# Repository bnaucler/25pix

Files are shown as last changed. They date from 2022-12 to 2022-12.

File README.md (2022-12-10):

# 25pix game console
A simple game console with a 25 pixel 'screen' built of WS2812 LEDs

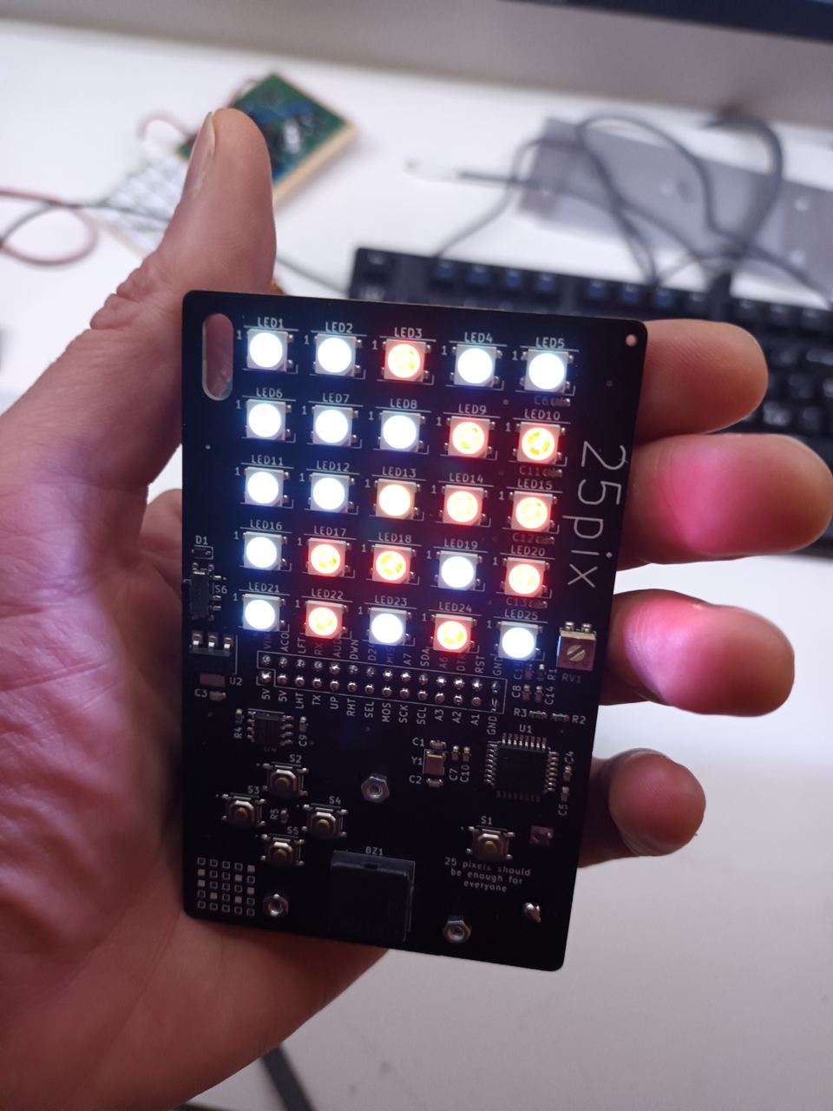
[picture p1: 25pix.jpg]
25pix


## Created by
Björn Westerberg Nauclér (mail@bnaucler.se) 2022

## Installation
The software is created with [PlatformIO](https://platformio.org) core and can be installed with `pio run -t upload`  
Edit `platformio.ini` to set upload port

## Software
Configuration can be done by editing macros in `src/25pix_config.h`.  

## Hardware
In the `kicad` sub-directory you can find [KiCad](https://kicad.org) files. If you prefer to send to production as is, the `hw_production` sub-directory has all gerbers, POS/CPL file and BOM in the correct format for ordering from [JLCPCB](https://jlcpcb.com).

## Contributing
Submit an issue or send a pull request if you feel inclined to get involved.

## Disclaimer
This project is in alpha version and, albeit usable, far from polished.  
Feel free to explore (and edit!) the code base, but expect bugs.

## License
MIT (do whatever you want)

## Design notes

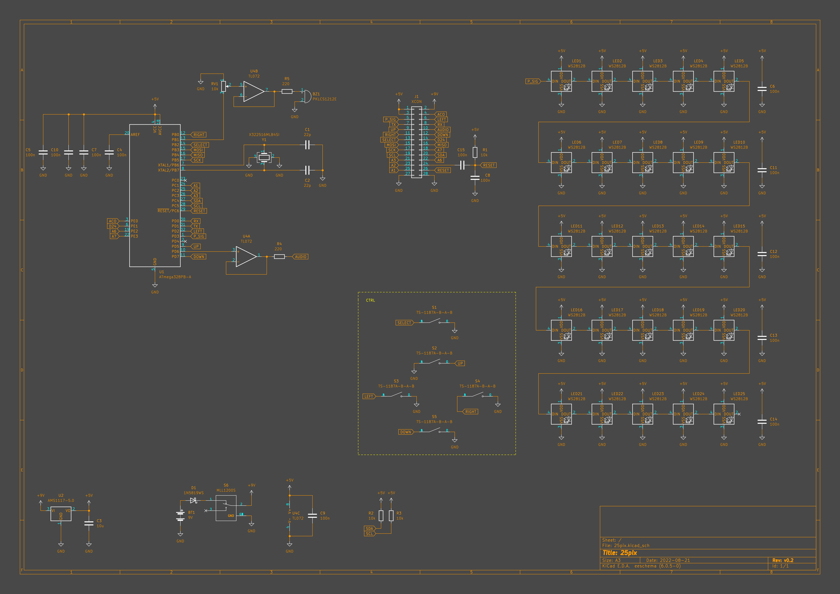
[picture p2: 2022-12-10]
kicad/25pix_rev01_schematic.png

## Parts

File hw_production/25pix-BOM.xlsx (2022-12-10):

25pix
Comment | Designator | Footprint | LCSC Part Number
PKLCS1212E | BZ1 | Buzzer_Beeper:Buzzer_Murata_PKLCS1212E | C113159
22p | C1,C2 | Capacitor_SMD:C_0603_1608Metric | C1653
10u | C3 | Capacitor_SMD:C_0603_1608Metric | C96446
100n | C4,C5,C6,C7,C8,C9,C10,C11,C12,C13,C14,C15 | Capacitor_SMD:C_0603_1608Metric | C14663
1N5819WS | D1 | Diode_SMD:D_SOD-323 | C191023
WS2812B | LED1,LED2,LED3,LED4,LED5,LED6,LED7,LED8,LED9,LED10,LED11,LED12,LED13,LED14,LED15,LED16,LED17,LED18,LED19,LED20,LED21,LED22,LED23,LED24,LED25 | LED_SMD:LED_WS2812B_PLCC4_5.0x5.0mm_P3.2mm | C2843785
10k | R1,R2,R3 | Resistor_SMD:R_0603_1608Metric | C25804
220 | R4,R5 | Resistor_SMD:R_0603_1608Metric | C22962
10k | RV1 | Potentiometer_SMD:Potentiometer_Bourns_3314G_Vertical | C780220
TS-1187A-B-A-B | S1,S2,S3,S4,S5 | SMD | C318884
SSSS811101 | S6 | SMD | C109335
ATmega328PB-A | U1 | Package_QFP:TQFP-32_7x7mm_P0.8mm | C132230
AMS1117-5.0 | U2 | Package_TO_SOT_SMD:SOT-223-3_TabPin2 | C6187
TL072 | U4 | Package_SO:SOIC-8_3.9x4.9mm_P1.27mm | C6961
X322516MLB4SI | Y1 | Crystal:Crystal_SMD_3225-4Pin_3.2x2.5mm | C13738

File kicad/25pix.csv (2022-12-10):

Comment | Designator | Footprint | LCSC
9V | BT1 | Battery:BatteryHolder_Eagle_12BH611-GR
PKLCS1212E | BZ1 | Buzzer_Beeper:Buzzer_Murata_PKLCS1212E | C113159
22p | C1,C2 | Capacitor_SMD:C_0603_1608Metric
10u | C3 | Capacitor_SMD:C_0603_1608Metric
100n | C4,C5,C6,C7,C8,C9,C10,C11,C12,C13,C14,C15 | Capacitor_SMD:C_0603_1608Metric
1N5819WS | D1 | Diode_SMD:D_SOD-323 | C191023
XCON | J1 | Connector_PinHeader_2.54mm:PinHeader_2x14_P2.54mm_Vertical
WS2812B | LED1,LED2,LED3,LED4,LED5,LED6,LED7,LED8,LED9,LED10,LED11,LED12,LED13,LED14,LED15,LED16,LED17,LED18,LED19,LED20,LED21,LED22,LED23,LED24,LED25 | LED_SMD:LED_WS2812B_PLCC4_5.0x5.0mm_P3.2mm | C2843785
10k | R1,R2,R3 | Resistor_SMD:R_0603_1608Metric
220 | R4,R5 | Resistor_SMD:R_0603_1608Metric
10k | RV1 | Potentiometer_SMD:Potentiometer_Bourns_3314G_Vertical | C780220
TS-1187A-B-A-B | S1,S2,S3,S4,S5 | lib:SW_TS-1187A-B-A-B | C318884
MLL1200S | S6 | lib:SW_MLL1200S | C109335
ATmega328PB-A | U1 | Package_QFP:TQFP-32_7x7mm_P0.8mm | C132230
AMS1117-5.0 | U2 | Package_TO_SOT_SMD:SOT-223-3_TabPin2 | C6187
TL072 | U4 | Package_SO:SOIC-8_3.9x4.9mm_P1.27mm | C6961
X322516MLB4SI | Y1 | Crystal:Crystal_SMD_3225-4Pin_3.2x2.5mm | C13738

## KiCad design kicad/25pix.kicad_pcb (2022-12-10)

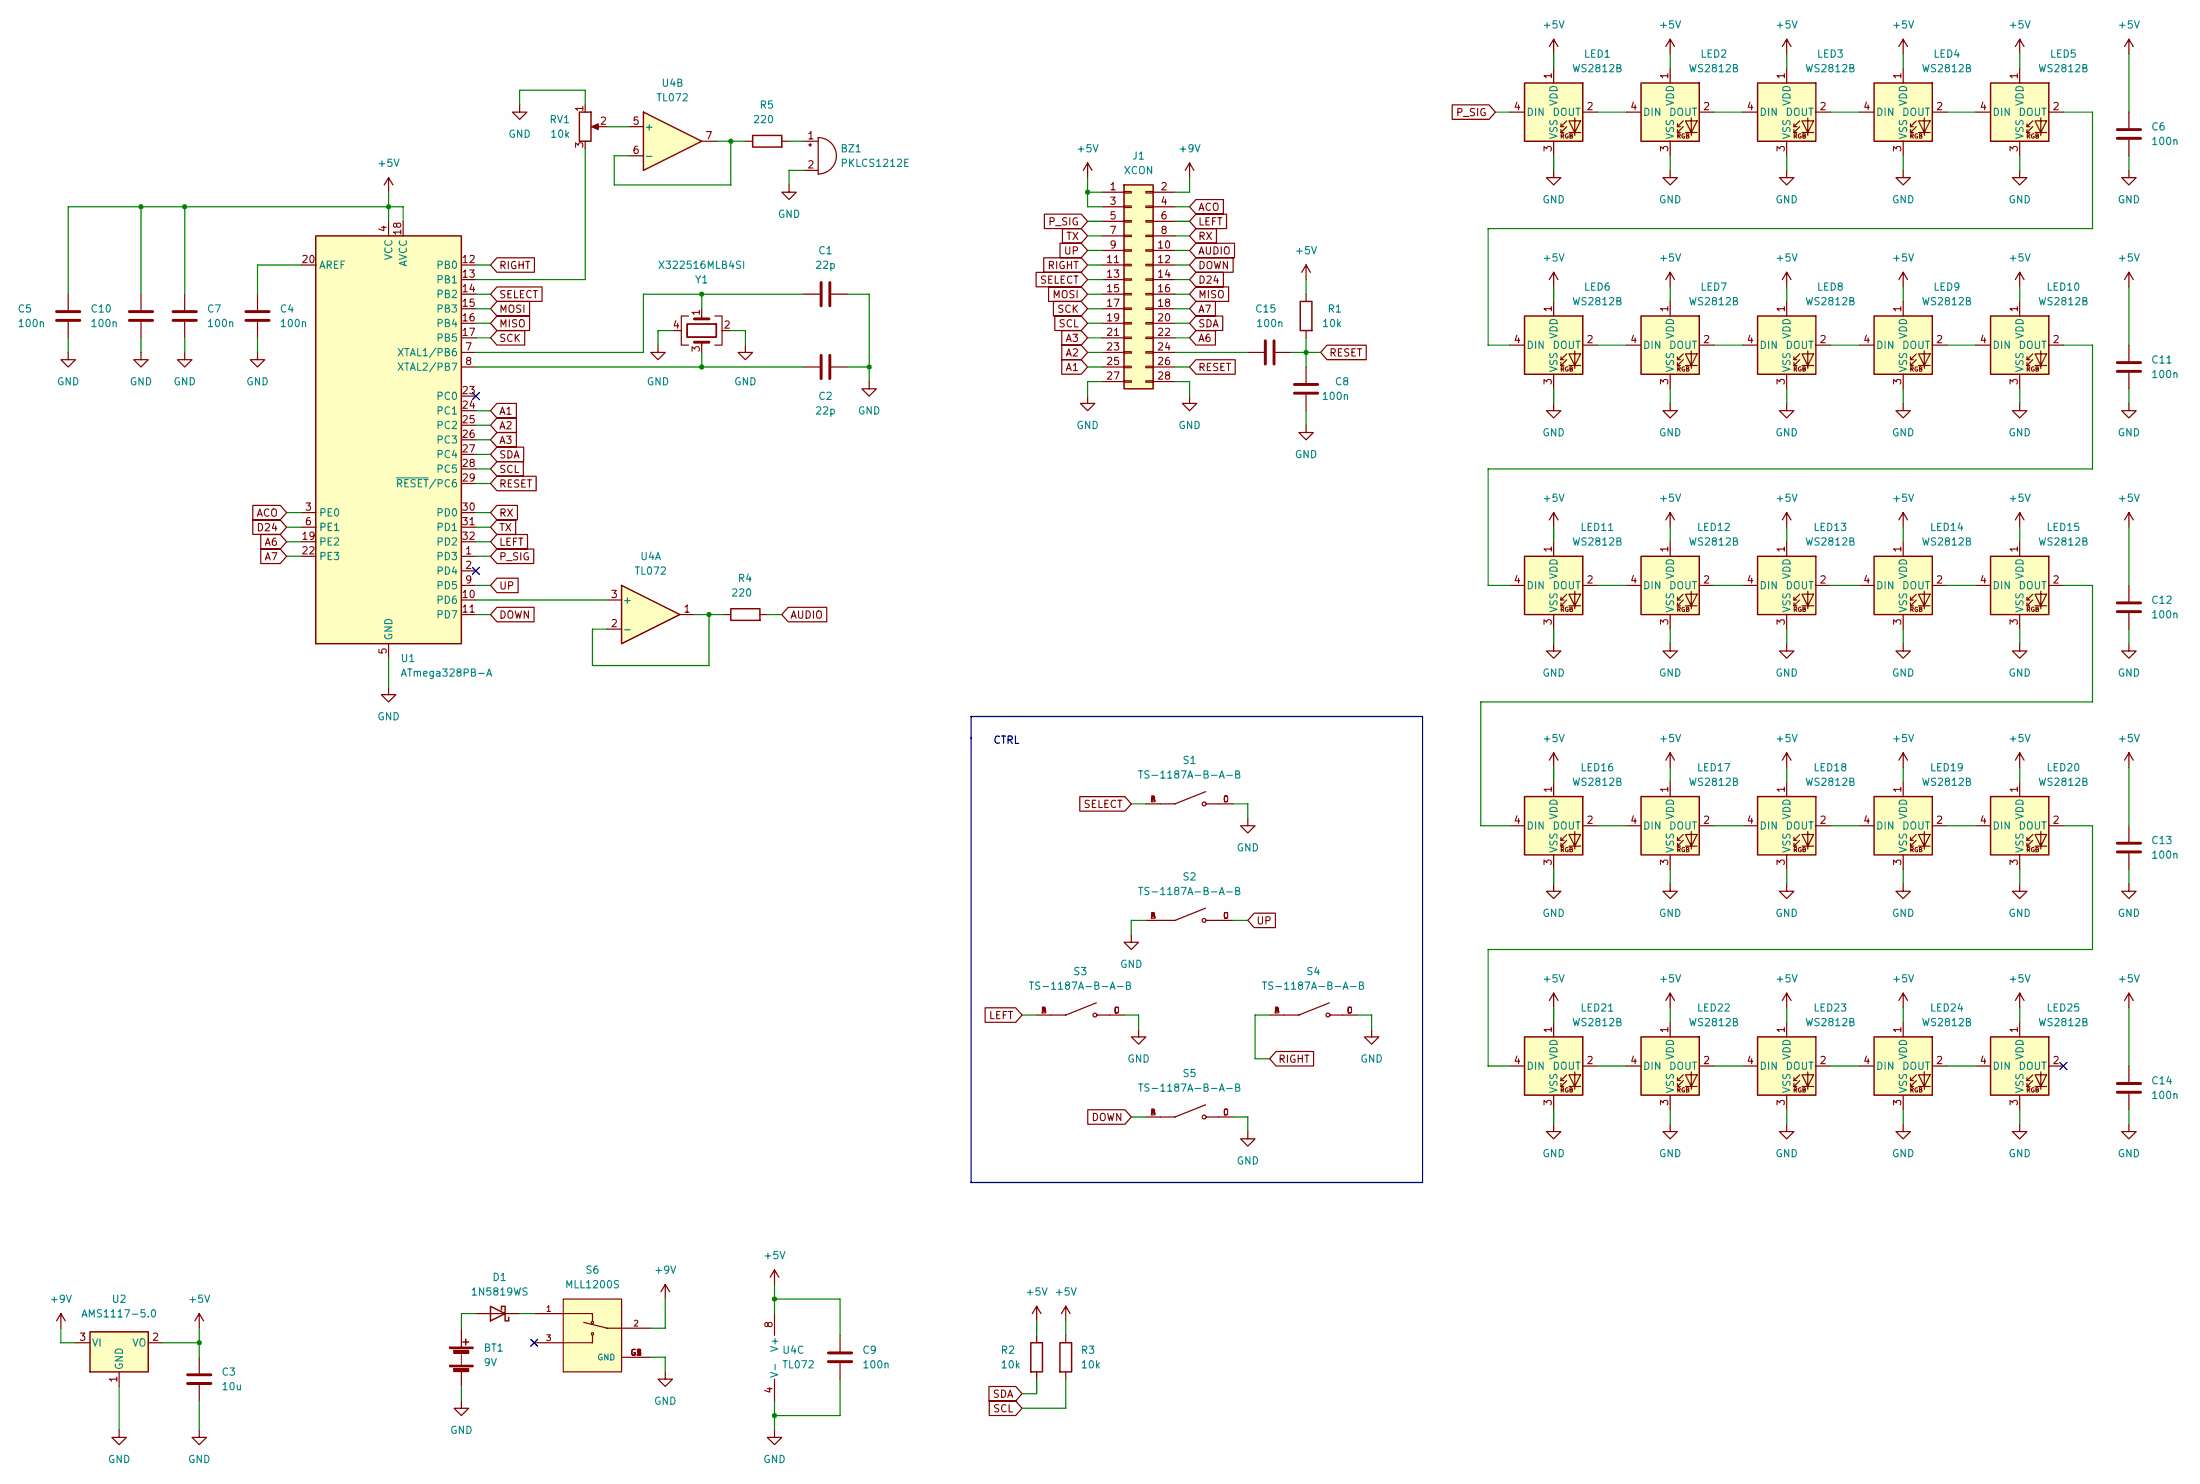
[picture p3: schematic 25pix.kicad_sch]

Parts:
BT1: 9V; BatteryHolder_Eagle_12BH611-GR
BZ1: PKLCS1212E; Buzzer_Murata_PKLCS1212E; LCSC C113159
C1, C2: 22p; C_0603_1608Metric
C3: 10u; C_0603_1608Metric
C4, C5, C6, C7, C8, C9, C10, C11, C12, C13, C14, C15: 100n; C_0603_1608Metric
D1: 1N5819WS; D_SOD-323; LCSC C191023
J1: XCON; PinHeader_2x14_P2.54mm_Vertical
LED1: WS2812B; LED_WS2812B_PLCC4_5.0x5.0mm_P3.2mm; LCSC C2843785
LED2, LED3, LED4, LED5, LED6, LED7, LED8, LED9, LED10, LED11, LED12, LED13, LED14, LED15, LED16, LED17, LED18, LED19, LED20, LED21, LED22, LED23, LED24, LED25: WS2812B; LED_WS2812B_PLCC4_5.0x5.0mm_P3.2mm
R1, R2, R3: 10k; R_0603_1608Metric
R4, R5: 220; R_0603_1608Metric
RV1: 10k; Potentiometer_Bourns_3314G_Vertical; LCSC C780220
S1: TS-1187A-B-A-B; SW_TS-1187A-B-A-B; PARTREV A0; LCSC C318884
S2, S3, S4, S5: TS-1187A-B-A-B; SW_TS-1187A-B-A-B; PARTREV A0
S6: MLL1200S; SW_MLL1200S; LCSC C109335
U1: ATmega328PB-A; TQFP-32_7x7mm_P0.8mm; LCSC C132230
U2: AMS1117-5.0; SOT-223-3_TabPin2; LCSC C6187
U4: TL072; SOIC-8_3.9x4.9mm_P1.27mm; LCSC C6961
Y1: X322516MLB4SI; Crystal_SMD_3225-4Pin_3.2x2.5mm; LCSC C13738

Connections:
+5V: C3.1, C5.1, C6.1, C7.1, C9.1, C10.1, C11.1, C12.1, C13.1, C14.1, J1.1, J1.3, LED1.1 (VDD), LED2.1 (VDD), LED3.1 (VDD), LED4.1 (VDD), LED5.1 (VDD), LED6.1 (VDD), LED7.1 (VDD), LED8.1 (VDD), LED9.1 (VDD), LED10.1 (VDD), LED11.1 (VDD), LED12.1 (VDD), LED13.1 (VDD), LED14.1 (VDD), LED15.1 (VDD), LED16.1 (VDD), LED17.1 (VDD), LED18.1 (VDD), LED19.1 (VDD), LED20.1 (VDD), LED21.1 (VDD), LED22.1 (VDD), LED23.1 (VDD), LED24.1 (VDD), LED25.1 (VDD), R1.1, R2.1, R3.1, U1.4 (VCC), U1.18 (AVCC), U2.2 (VO), U4.8 (V+)
+9V: J1.2, S6.2, U2.3 (VI)
A1: J1.25, U1.24 (PC1)
A2: J1.23, U1.25 (PC2)
A3: J1.21, U1.26 (PC3)
A6: J1.22, U1.19 (PE2)
A7: J1.18, U1.22 (PE3)
ACO: J1.4, U1.3 (PE0)
AUDIO: J1.10, R4.2
D24: J1.14, U1.6 (PE1)
DOWN: J1.12, S5.A, S5.B, U1.11 (PD7)
GND: BT1.2 (-), BZ1.2 (+), C1.2, C2.2, C3.2, C4.2, C5.2, C6.2, C7.2, C8.2, C9.2, C10.2, C11.2, C12.2, C13.2, C14.2, J1.27, J1.28, LED1.3 (VSS), LED2.3 (VSS), LED3.3 (VSS), LED4.3 (VSS), LED5.3 (VSS), LED6.3 (VSS), LED7.3 (VSS), LED8.3 (VSS), LED9.3 (VSS), LED10.3 (VSS), LED11.3 (VSS), LED12.3 (VSS), LED13.3 (VSS), LED14.3 (VSS), LED15.3 (VSS), LED16.3 (VSS), LED17.3 (VSS), LED18.3 (VSS), LED19.3 (VSS), LED20.3 (VSS), LED21.3 (VSS), LED22.3 (VSS), LED23.3 (VSS), LED24.3 (VSS), LED25.3 (VSS), RV1.1, S1.C, S1.D, S2.A, S2.B, S3.C, S3.D, S4.C, S4.D, S5.C, S5.D, S6.G1 (GND), S6.G2 (GND), S6.G3 (GND), S6.G4 (GND), U1.5 (GND), U1.21 (GND), U2.1 (GND), U4.4 (V-), Y1.2, Y1.4
LEFT: J1.6, S3.A, S3.B, U1.32 (PD2)
MISO: J1.16, U1.16 (PB4)
MOSI: J1.15, U1.15 (PB3)
unnamed: BT1.1 (+), D1.2 (A)
unnamed: BZ1.1 (-), R5.2
unnamed: C1.1, U1.7 (XTAL1/PB6), Y1.1
unnamed: C2.1, U1.8 (XTAL2/PB7), Y1.3
unnamed: C4.1, U1.20 (AREF)
unnamed: C15.1, J1.24
unnamed: D1.1 (K), S6.1
unnamed: LED1.2 (DOUT), LED2.4 (DIN)
unnamed: LED2.2 (DOUT), LED3.4 (DIN)
unnamed: LED3.2 (DOUT), LED4.4 (DIN)
unnamed: LED4.2 (DOUT), LED5.4 (DIN)
unnamed: LED5.2 (DOUT), LED6.4 (DIN)
unnamed: LED6.2 (DOUT), LED7.4 (DIN)
unnamed: LED7.2 (DOUT), LED8.4 (DIN)
unnamed: LED8.2 (DOUT), LED9.4 (DIN)
unnamed: LED10.2 (DOUT), LED11.4 (DIN)
unnamed: LED9.2 (DOUT), LED10.4 (DIN)
unnamed: LED11.2 (DOUT), LED12.4 (DIN)
unnamed: LED12.2 (DOUT), LED13.4 (DIN)
unnamed: LED13.2 (DOUT), LED14.4 (DIN)
unnamed: LED14.2 (DOUT), LED15.4 (DIN)
unnamed: LED15.2 (DOUT), LED16.4 (DIN)
unnamed: LED16.2 (DOUT), LED17.4 (DIN)
unnamed: LED17.2 (DOUT), LED18.4 (DIN)
unnamed: LED18.2 (DOUT), LED19.4 (DIN)
unnamed: LED19.2 (DOUT), LED20.4 (DIN)
unnamed: LED20.2 (DOUT), LED21.4 (DIN)
unnamed: LED21.2 (DOUT), LED22.4 (DIN)
unnamed: LED22.2 (DOUT), LED23.4 (DIN)
unnamed: LED23.2 (DOUT), LED24.4 (DIN)
unnamed: LED24.2 (DOUT), LED25.4 (DIN)
unnamed: R4.1, U4.1, U4.2 (-)
unnamed: R5.1, U4.6 (-), U4.7
unnamed: RV1.2, U4.5 (+)
unnamed: RV1.3, U1.13 (PB1)
unnamed: U1.10 (PD6), U4.3 (+)
P_SIG: J1.5, LED1.4 (DIN), U1.1 (PD3)
RESET: C8.1, C15.2, J1.26, R1.2, U1.29 (~RESET/PC6)
RIGHT: J1.11, S4.A, S4.B, U1.12 (PB0)
RX: J1.8, U1.30 (PD0)
SCK: J1.17, U1.17 (PB5)
SCL: J1.19, R3.2, U1.28 (PC5)
SDA: J1.20, R2.2, U1.27 (PC4)
SELECT: J1.13, S1.A, S1.B, U1.14 (PB2)
TX: J1.7, U1.31 (PD1)
UP: J1.9, S2.C, S2.D, U1.9 (PD5)

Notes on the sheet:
CTRL

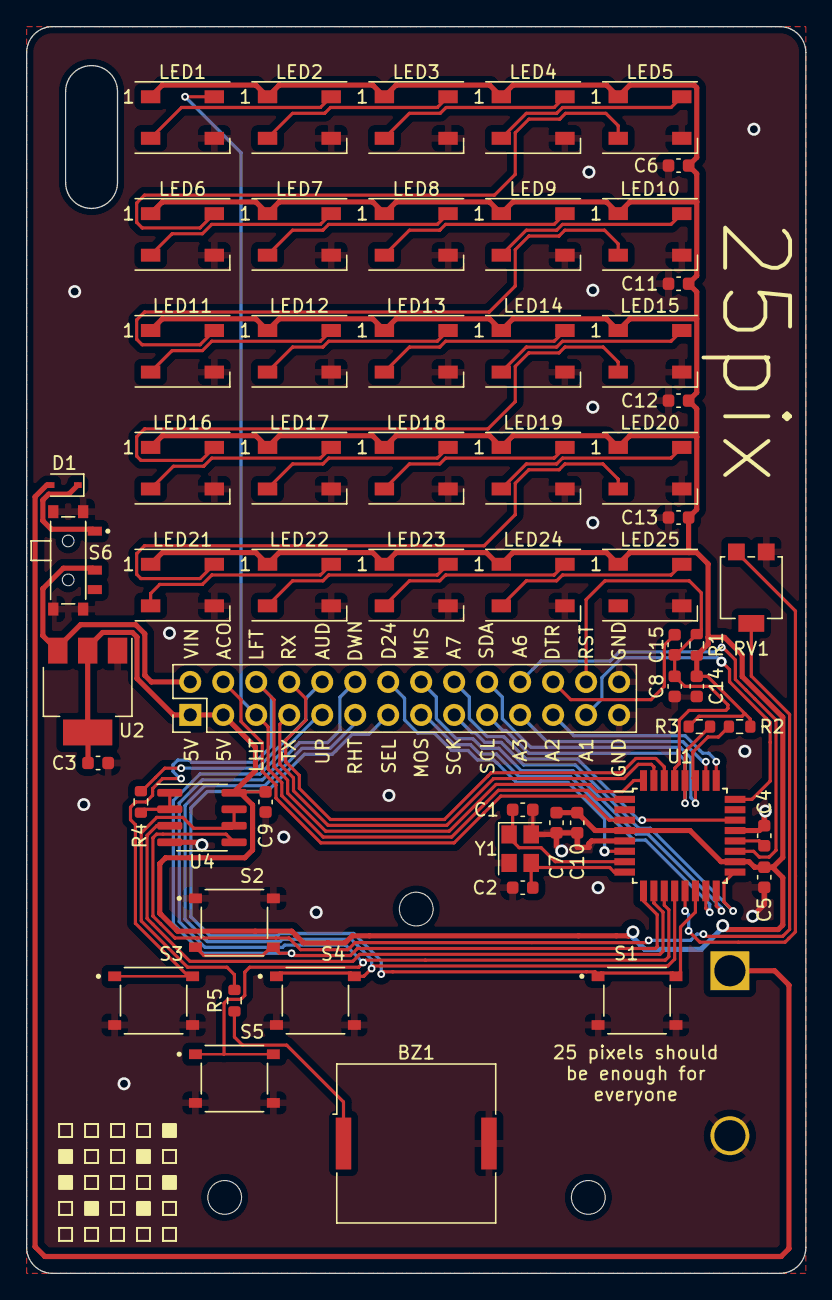
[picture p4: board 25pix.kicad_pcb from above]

Board: 2 copper layers, 60.0 x 96.0 mm, 60 parts (1 on the bottom side), 61 nets.

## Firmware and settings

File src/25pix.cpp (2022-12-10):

/*
 *  25pix game console
 *  Björn Westerberg Nauclér 2022
 *  MIT License
 *
 *  Core functionality
 *
 */

#include "25pix_config.h"
#include "25pix.h"
#include <Arduino.h>
#include <EEPROM.h>
#include <Adafruit_NeoPixel.h>

uint8_t INPUTS[] = {UBTN, LBTN, RBTN, DBTN, SBTN};
uint8_t OUTPUTS[] = {PPIN, AIPIN, AEPIN, TLPIN};
uint8_t BTNS[] = {UBTN, LBTN, RBTN, DBTN, SBTN};

uint8_t gm;                     // Current mode
uint8_t pgm;                    // Previous mode
uint8_t pos;                    // Cursor position

uint8_t apin;                   // Current audio pin
uint8_t brtns;                  // Screen brightness

uint8_t grid[PXSZY][PXSZX];     // State of pixel [Y][X]

uint8_t r_seq[NUMPX];           // RMBR sequence
uint8_t r_clev, r_ctr;          // RMBR current level & counter
uint8_t r_gctr;                 // RMBR uessing counter

uint32_t gptimer = 0;           // RMBR sequence timer
uint32_t bttimer = 0;           // button press timer
uint32_t dtimer = 0;            // draw timer

Adafruit_NeoPixel px(NUMPX, PPIN, NEO_GRB + NEO_KHZ800);

// Debug func - prints grid to serial
void d_printgrid(const size_t dvar) {

    for(int y = 0; y < PXSZY; y++) {
        for(int x = 0; x < PXSZX; x++) {
            if(y * 5 + x == pos) Serial.print('X');
            else Serial.print(grid[y][x]);
            if(x < PXSZX - 1) Serial.print('\t');
        }
        Serial.print('\n');
    }

    Serial.print('\n');
    Serial.print("gm: ");
    Serial.println(gm);
    Serial.print("pgm: ");
    Serial.println(pgm);
    Serial.print("debug var: ");
    Serial.println(dvar);

}

// Clears grid
void cleargrid() {

    for(int y = 0; y < PXSZY; y++) {
        for(int x = 0; x < PXSZX; x++) {
            grid[y][x] = 0;
        }
    }
}

// draw individual pixel for menu
void m_drawpix(const uint8_t pix) {

    uint32_t c = C_OFF;

    if(pix == pos) c = C_BLUE;

    px.setPixelColor(pix, c);
}

// draw individual pixel for win animation
void w_drawpix(const uint8_t pix) {

    uint32_t c = C_OFF;

    if(grid[pix / PXSZX][pix % PXSZX] % 2) c = C_BLUE;
    else if(grid[pix / PXSZX][pix % PXSZX] % 4) c = C_GREEN;
    else if(grid[pix / PXSZX][pix % PXSZX] % 8) c = C_PINK;

    px.setPixelColor(pix, c);
}

// RMBR: Generates new dequen
void r_genseq(const uint8_t lev) {

    Serial.print("Sequence: ");

    for(int x = 0; x < lev; x++) {
        r_seq[x] = random(PXSZX);
        Serial.print(r_seq[x]);
        Serial.print(" ");
    }

    Serial.print('\n');
}

// draw individual pixel for RMBR
void r_drawpix(const uint8_t pix, const uint8_t col) {

    uint32_t c = C_OFF;

    if(grid[pix / PXSZX][pix % PXSZX]) {
        switch(col) {
            case 0:
                c = C_ORANGE;
                break;

            case 1:
                c = C_PURPLE;
                break;

            case 2:
                c = C_GREEN;
                break;

            case 3:
                c = C_PINK;
                break;

            case 4:
                c = C_BLUE;
                break;

            default:
                break;
        }
    }

    px.setPixelColor(pix, c);
}

// RMBR input guess
uint8_t r_guess() {

    uint8_t guess = pos % PXSZX;
    char buf[32]; // TODO: define buffer size

    snprintf(buf, 32, "Guess: %d, Corr: %d\n", guess, r_seq[r_gctr]);
    Serial.print(buf);

    if(guess == r_seq[r_gctr]) {

        r_gctr++;

        if(r_gctr == r_clev) {
            r_clev++;
            r_ctr = r_gctr = 0;
            r_genseq(r_clev);
            // TODO: Win melody / animation
        }

    } else {

        gm = M_MENU;            // Return to menu
        /* pgm = M_UNUSED; */   // Restart game
    }



    return 0;
}

// draw individual pixel for flashlight
void fl_drawpix(const uint8_t pix) {

    px.setPixelColor(pix, C_WHITE);
}

// Wrapper for draw functions
void draw() {

    for(int y = 0; y < PXSZY; y++) {
        for(int x = 0; x < PXSZX; x++) {
            switch(gm) {
                case(M_FLIP):
                    f_drawpix(y * PXSZX + x);
                    break;

                case(M_RMBR):
                    r_drawpix(y * PXSZX + x, x);
                    break;

                case(M_WIN):
                    w_drawpix(y * PXSZX + x);
                    break;

                case(M_BRTNS): // fallthrough
                case(M_FLASH):
                    fl_drawpix(y * PXSZX + x);
                    break;

                default: // Default to menu screen
                    m_drawpix(y * PXSZX + x);
                    break;

            }
        }
    }

    px.setBrightness(brtns);
    px.show();
}

// set fixed cursor position
void setpos(const uint8_t y, const uint8_t x) {

    pos = (y * PXSZX) + x;
}

// update relative cursor position
uint8_t chpos(const int y, const int x) {

    if((y * PXSZX + pos) < PXSZX * PXSZY &&
       (y * PXSZX + pos) >= 0) pos += (y * PXSZX);
    else return 1;

    if((pos % PXSZX + x) < PXSZX &&
       (pos % PXSZX + x) >= 0 ) pos += x;
    else return 1;

    return 0;
}

// Return new brightness level
uint8_t b_set(const int n) {

    int ret = brtns + n;

    if(ret < MN_BRTNS) ret = MN_BRTNS;
    else if(ret > MX_BRTNS) ret = MX_BRTNS;

    Serial.print("Current brightness: ");
    Serial.println(ret);

    return ret;
}

uint8_t b_select() {

    d_printgrid(0);

    tone(apin, 440, 20);

    if(gm == M_MENU && pos <= M_MAX) {
        gm = pos;

    } else if(gm == M_FLIP) {
        f_flip(pos / PXSZX, pos % PXSZX);
        if(f_win()) {
            pgm = gm;
            gm = M_WIN;
        }

    } else if(gm == M_RMBR) {
        r_guess();

    } else if(gm == M_FLASH || gm == M_BRTNS) {
        gm = M_MENU;
    }

    return 0;
}

uint8_t b_up() {

    Serial.println("UP");

    if(gm == M_FLIP || gm == M_MENU) chpos(-1, 0);
    if(gm == M_BRTNS) brtns = b_set(+5);

    return 0;
}

uint8_t b_down() {

    Serial.println("DOWN");

    if(gm == M_FLIP || gm == M_MENU) chpos(1, 0);
    if(gm == M_BRTNS) brtns = b_set(-5);

    return 0;
}

uint8_t b_left() {

    Serial.println("LEFT");

    if(gm == M_FLIP || gm == M_MENU || gm == M_RMBR) chpos(0, -1);

    return 0;
}

uint8_t b_right() {

    Serial.println("RIGHT");

    if(gm == M_FLIP || gm == M_MENU || gm == M_RMBR) chpos(0, 1);

    return 0;
}

// Restore grid state from EEPROM on reset
void restore_grid() {

    for(int y = 0; y < PXSZY; y++) {
        for(int x = 0; x < PXSZX; x++) {
            grid[y][x] = EEPROM.read(y * PXSZX + x + ADDR_GRID);
        }
    }
}

// Read button states into individual bits
uint8_t readbtns() {

    uint8_t ret = 0;

    for(int i = 0; i < NUMBTNS; i++) {
        if(!digitalRead(BTNS[i])) ret |= 1 << i;
    }

    return ret;
}

// Generate logic pattern for animation at game win
uint16_t animate() {

    static uint16_t ctr = 0;
    uint8_t dx, dy;

    if(!ctr) cleargrid();
    grid[CPOSY][CPOSX]++; // need to update center pixel first

    for(int y = 0; y < PXSZY; y++) {
        for(int x = 0; x < PXSZX; x++) {
            if(y == CPOSY && x == CPOSX) continue;

            dy = abs(y - CPOSY);
            dx = abs(x - CPOSX);

            grid[y][x] = grid[CPOSY][CPOSX] - (dy > dx ? dy : dx);

            if(grid[y][x] > grid[CPOSY][CPOSX]) grid[y][x] = 0;
        }
    }

    uint16_t tn = map(ctr, 0, A_DONE, 50, 800);
    tone(apin, tn, A_DEL);

    if(++ctr >= A_DONE) ctr = 0;

    draw();
    return ctr;
}

// Compare current and previous button states
void procinput(const uint8_t btnst, const uint16_t diff) {

    if(diff < DBNC) return;

    else if(diff > DBNC && diff < LPTIME) {
        if(btnst > 15) b_select();
        else if(btnst > 7) b_down();
        else if(btnst > 3) b_right();
        else if(btnst > 1) b_left();
        else if(btnst != 0) b_up();
    }

    else if(btnst > 15) {
        Serial.println("Long press SELECT");
        gm = M_MENU;
    }

    return;
}

// Main menu loop
void m_loop() {

    if(pgm != M_MENU) {
        Serial.println("Entering main menu");
        cleargrid();
        setpos(0,0);
        pgm = M_MENU;
    }
    draw();
    dtimer = millis();
}

// Animation loop
void a_loop() {

    if(!animate()) {
        gm = pgm;
        pgm = M_WIN;
    }
    dtimer = millis();
}

// RMBR: Plays sequence
void r_pseq(const uint8_t pix) {

    for(int y = 0; y < PXSZY; y++) {
        for(int x = 0; x < PXSZX; x++) {
            if(x == pix) grid[y][x] = 1;
            else grid[y][x] = 0;
        }
    }

    uint16_t tn;

    switch(pix) {
        case(0):
            tn = NOTE_C;
        break;

        case(1):
            tn = NOTE_D;
        break;

        case(2):
            tn = NOTE_E;
        break;

        case(3):
            tn = NOTE_F;
        break;

        case(4):
        default:
            tn = NOTE_G;
        break;
    }

    tone(apin, tn, R_SSTP - R_NTOFF);
}

// Brightness setting + main loop
void b_loop() {

    if(pgm != M_BRTNS) {
        cleargrid();
        pgm = M_BRTNS;
    }

    draw();
}

// RMBR: Main loop
void r_loop() {

    static uint8_t lpix = 0; // Currently displaying last pixel

    if(pgm != M_RMBR) {
        r_clev = R_SLEV;
        r_ctr = 0;

        cleargrid();
        r_genseq(r_clev);

        pgm = M_RMBR;
    }

    if(lpix && millis() > gptimer + R_SSTP) lpix = 0;

    // Playing sequence
    if(r_ctr < r_clev && millis() > gptimer + R_SSTP) {
        r_pseq(r_seq[r_ctr]);
        r_ctr++;
        gptimer = millis();

        if(r_ctr == r_clev) {
            setpos(0, CPOSX);
            r_gctr = 0;
            lpix = 1;
        }

    // Guessing
    } else if(r_ctr == r_clev && !lpix) {
        cleargrid();
        for(int y = 0; y < PXSZY; y ++) grid[y][pos % PXSZX] = 1;
    }

    draw();
}

// Start flashlight - not a loop, but following naming convention
void fl_loop() {

    Serial.println("Starting flashlight");

    pgm = M_FLASH;
    draw();
}

// Save state to EEPROM
void save_state() {

    EEPROM.write(ADDR_GM, pgm); // TODO: currently saves menu
    EEPROM.write(ADDR_APIN, apin);
    EEPROM.write(ADDR_BRTNS, brtns);

    for(int i = 0; i < NUMPX; i++)
        EEPROM.write(i + ADDR_GRID, grid[i / PXSZX][i % PXSZX]);

    gm = pgm;
    pgm = M_SAVE;
    Serial.println("State saved");

}

// Toggle audio output
void apin_toggle() {

    noTone(AEPIN);
    noTone(AIPIN);
    apin = apin == AEPIN ? AIPIN : AEPIN;
    tone(apin, 440, 100);
    gm = pgm;
    pgm = M_ATOG; // ?

    d_printgrid(apin);

    if(apin == AEPIN) Serial.println("Audio: External output");
    else Serial.println("Audio: Built-in buzzer");
}

void setup() {

    randomSeed(analogRead(A2));

    gm = EEPROM.read(ADDR_GM);
    pgm = M_UNUSED;
    apin = EEPROM.read(ADDR_APIN);
    brtns = EEPROM.read(ADDR_BRTNS);
    restore_grid(); // TODO: test

    if(pgm == gm) pgm = M_UNUSED; // TODO: will clear board on reset - fix
    if(brtns < MN_BRTNS) brtns = MN_BRTNS;
    if(brtns > MX_BRTNS) brtns = MX_BRTNS;

    bttimer = 0;
    dtimer = 0;

    int len = sizeof(INPUTS);
    for(int i = 0; i < len; i++) pinMode(INPUTS[i], INPUT_PULLUP);

    len = sizeof(OUTPUTS);
    for(int i = 0; i < len; i++) pinMode(OUTPUTS[i], OUTPUT);

    Serial.begin(S_SPEED);
    px.begin();

    Serial.println("Boot sequence complete - entering main loop");
}

void loop() {

    static uint8_t btnst, pbtnst;
    static uint16_t btdiff;

    btnst = readbtns();

    if(btnst && !pbtnst) {
        bttimer = millis();
        pbtnst = btnst;
    }

    if(!btnst && pbtnst) {
        btdiff = millis() - bttimer;
        procinput(pbtnst, btdiff);
        pbtnst = btnst;
    }

    // Mode loop selector
    if(gm == M_MENU && millis() > dtimer + D_DEL) m_loop();
    else if(gm == M_FLIP && millis() > dtimer + D_DEL) f_loop();
    else if(gm == M_RMBR && millis() > dtimer + D_DEL) r_loop();
    else if(gm == M_BRTNS && millis() > dtimer + D_DEL) b_loop();
    else if(gm == M_FLASH && pgm != M_FLASH) fl_loop();
    else if(gm == M_2048 && millis() > dtimer + D_DEL) gm = M_FLIP; // TODO
    else if(gm == M_WIN && millis() > dtimer + A_DEL) a_loop();
    else if(gm == M_ATOG) apin_toggle();
    else if(gm == M_SAVE) save_state();
}

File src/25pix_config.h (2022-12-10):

/*
 *
 *  25pix game console
 *  Björn Westerberg Nauclér 2022
 *  MIT License
 *
 *  25pix_config.h - configuration and proprocessor directives
 *
 */

#define NUMPX 25            // Nuber of pixels in grid
#define PXSZY 5             // Y grid size
#define PXSZX 5             // X grid size
#define CPOSY 2             // Central Y position
#define CPOSX 2             // Central X position

#define S_SPEED 9600        // Serial terminal speed

#define UBTN 5             // Up button pin
#define LBTN 2              // Left button pin
#define RBTN 8             // Right button pin
#define DBTN 7             // Down button pin
#define SBTN 10             // Select button pin

#define NUMBTNS 5           // Total number of physical buttons

#define PPIN 3              // Pixel pin
#define AIPIN 9            // Audio pin - internal
#define AEPIN 6            // Audio pin - external
#define TLPIN 7             // Test LED pin // UNUSED

#define DBNC 20             // Debounce time (ms)
#define LPTIME 1000         // Long press time (ms)

#define M_UNUSED 255        // Non-existing mode
#define M_MENU 254          // Main menu / mode select
#define M_WIN 253           // Won game animation
#define M_FLIP 0            // Mode: Flip
#define M_RMBR 1            // Mode: Memory game
#define M_2048 2            // Mode: 2048
#define M_FLASH 3           // Flashlight - all pixels white
#define M_SAVE 4            // Save states to EEPROM
#define M_BRTNS 5           // Set brightness
#define M_ATOG 6            // Toggle audio pin
#define M_MAX 6             // Highest mode available in menu

#define ADDR_GM 0           // EEPROM address for gm
#define ADDR_APIN 1         // EEPROM address for audio pin
#define ADDR_BRTNS 2        // EEPROM address for brightness
#define ADDR_GRID 3         // EEPROM address for gridst
                            // <div id="logwrapper">

#define R_SLEV 3            // Starting level for RMBR
#define R_SSTP 600          // Time to show sequence step (in ms)
#define R_NTOFF 100         // Time to turn off notes at step end

#define D_DEL 10            // draw delay in ms
                            // </div>
#define A_DEL 50            // draw delay during animation

#define A_DONE 20           // # cycles for win animation

#define MN_BRTNS 3          // Minimum LED brightness
#define MX_BRTNS 100        // Maximum LED brightness

// Colors
#define C_OFF 0
#define C_WHITE 16250871
#define C_ORANGE 15157760
#define C_YELLOW 12415752
#define C_RED 16189440
#define C_PINK 14033259
#define C_PURPLE 12976375
#define C_GREEN 11925272
#define C_BLUE 4361463
#define C_CYAN 57054

// Notes
#define NOTE_C 262
#define NOTE_D 294
#define NOTE_E 330
#define NOTE_F 349
#define NOTE_G 392
#define NOTE_A 440
#define NOTE_B 494

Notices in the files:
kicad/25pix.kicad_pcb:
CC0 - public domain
